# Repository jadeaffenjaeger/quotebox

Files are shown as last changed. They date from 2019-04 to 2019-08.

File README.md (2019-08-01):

## Quotebox
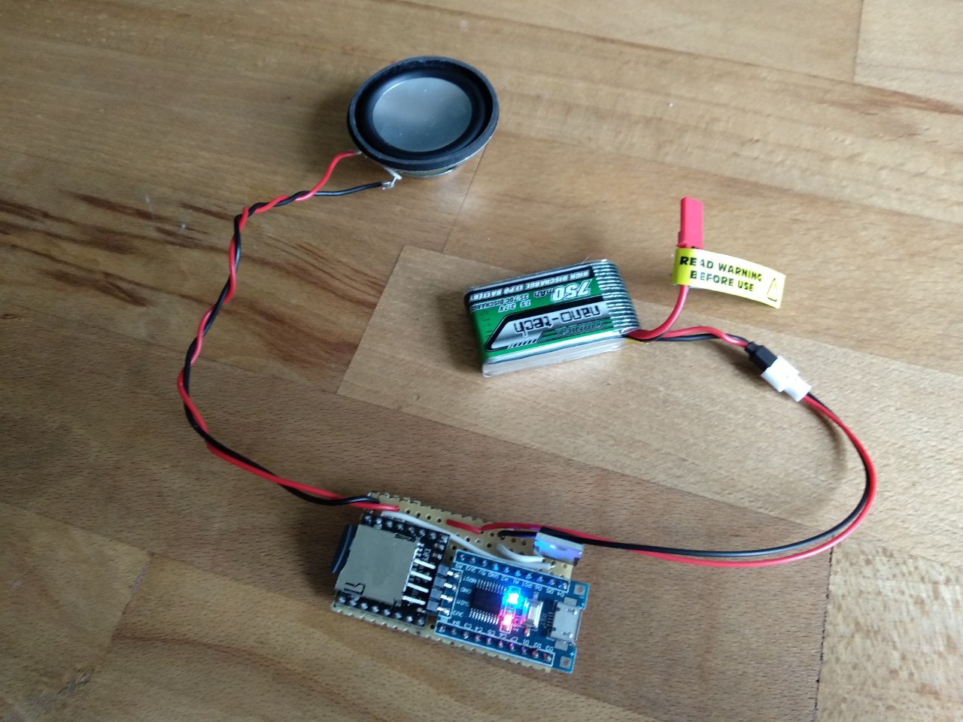
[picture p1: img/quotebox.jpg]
Quotebox Picture

This piece of electronics was made for an installation where speakers at various places would play short bits of sound at random intervals. Since there was no power available, the speakers need to run off 1S LiPo batteries. Since the budget was quite low, only cheap and easy to source components were used.

### Components
A DFPlayer mini module is used to play mp3 sound bites from an SD card. Since the Idle Power consumption of the DFPlayer is quite high, even when in Standby mode, an external STM8 microcontroller is used to power up the DFPlayer through a MOSFET when needed and power it down as soon as it has finished playing. The STM8 also keeps track of sleep times and which track on the card to play next.
The components used are:
- [DFPlayer Mini](https://wiki.dfrobot.com/DFPlayer_Mini_SKU_DFR0299)
- [STM8S103 Breakout Board](https://github.com/TG9541/stm8ef/wiki/Breakout-Boards#stm8s103f3p6-breakout-board)
- [IRLZ44N MOSFET](http://www.irf.com/product-info/datasheets/data/irlz44n.pdf)
- [HobbyKing 1S 750mAh LiPo](https://hobbyking.com/en_us/turnigy-nano-tech-750mah-1s-35-70c-lipo-pack-fits-nine-eagles-solo-pro-180.html)

summing up to below 5€ per speaker (without battery)

### Energy
750mAh LiPo batteries from HobbyKing were used to power each speaker as I had them laying around from my drone anyway. Both the STM8 and DFPlayer work with 3-5V, so no voltage regulator was needed, keeping the price down. The voltage of the LiPo is not checked by the microcontroller, however, so the circuit will deep-discharge the battery if left unattended for too long. For our use case, the speakers played a sound of ca. 5s every few minutes. The STM8 needs ca. 2mA when in sleep mode (mostly
due to the power LED on the breakout board. If lower consumption is required, one should remove the LED). The DFPlayer consumes 50-120mA when playing a file (depending on the content of the file). All in all, the speakers would have been able to work for 2-3 days on a single LiPo.

### Firmware
The firmware for the STM8 is in the `src` folder. The DFPlayer is addressed over UART via the `dfplayer.c` module, the `awu.c` sends the microcontroller to sleep and the external MOSFET that powers the DFPlayer on and off is switched in the `gpio.c` file, along with the user LED.
The firmware can be built with SDCC using `make all` and uploaded to a board with `make flash`. An STLink (clone) and [stm8flash] are required for this. If you run into problems uploading to a new board, you might try unlocking it using `make unlock`

[stm8flash]: https://github.com/vdudouyt/stm8flash

### Schematics
I tried started doing a custom PCB for the speakers, but ended up opting for Perf Board eventually. The PCB layout therefore is not up to date and should not be used as is.

### Housing
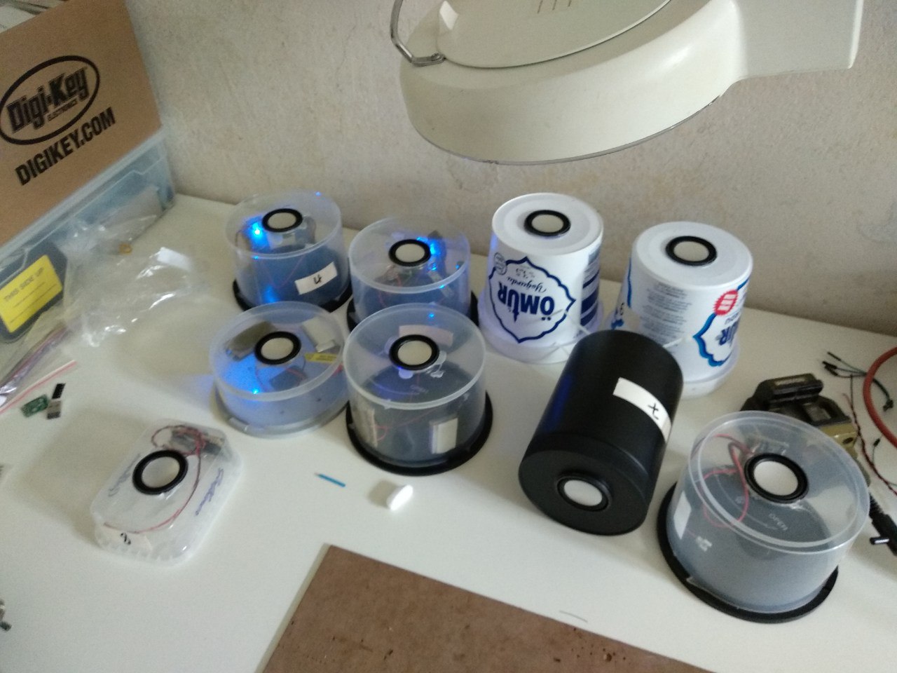
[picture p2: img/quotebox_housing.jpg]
Quotebox Housing

Again, to keep cost low, the speakers were hot-glued into old CD-R spindles to give them some protection and improve the resonance of the speaker

### Summary
The speakers at full volume were loud enough to be heard indoors. The ones installed outdoors (in a rather noisy environment) were quite hard understand from a few meters away already, so a bigger speaker and amp would be required for this to work.

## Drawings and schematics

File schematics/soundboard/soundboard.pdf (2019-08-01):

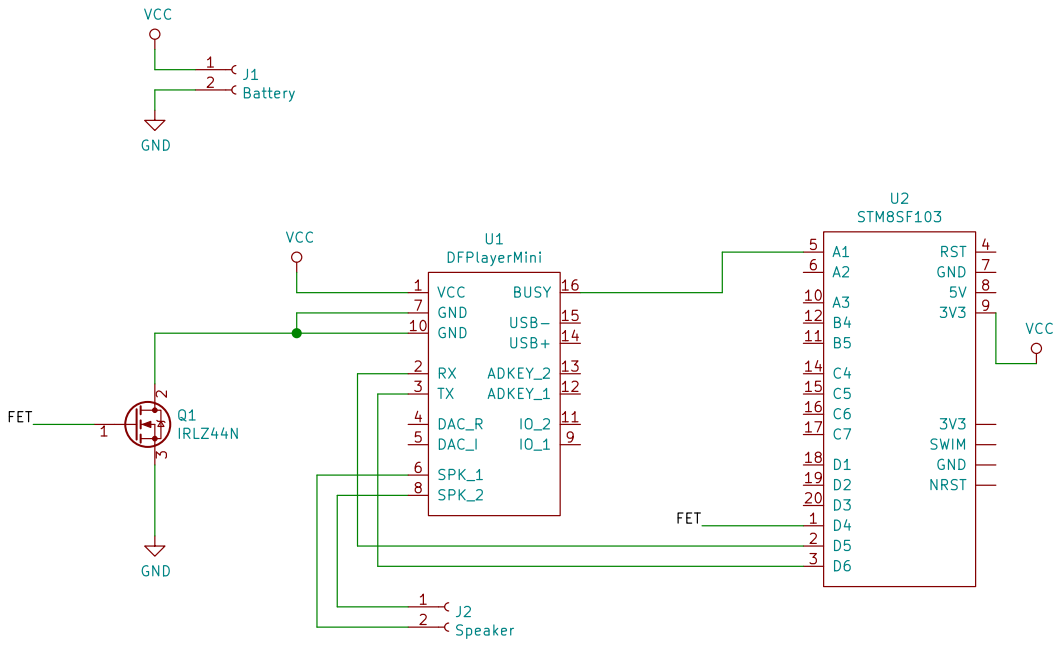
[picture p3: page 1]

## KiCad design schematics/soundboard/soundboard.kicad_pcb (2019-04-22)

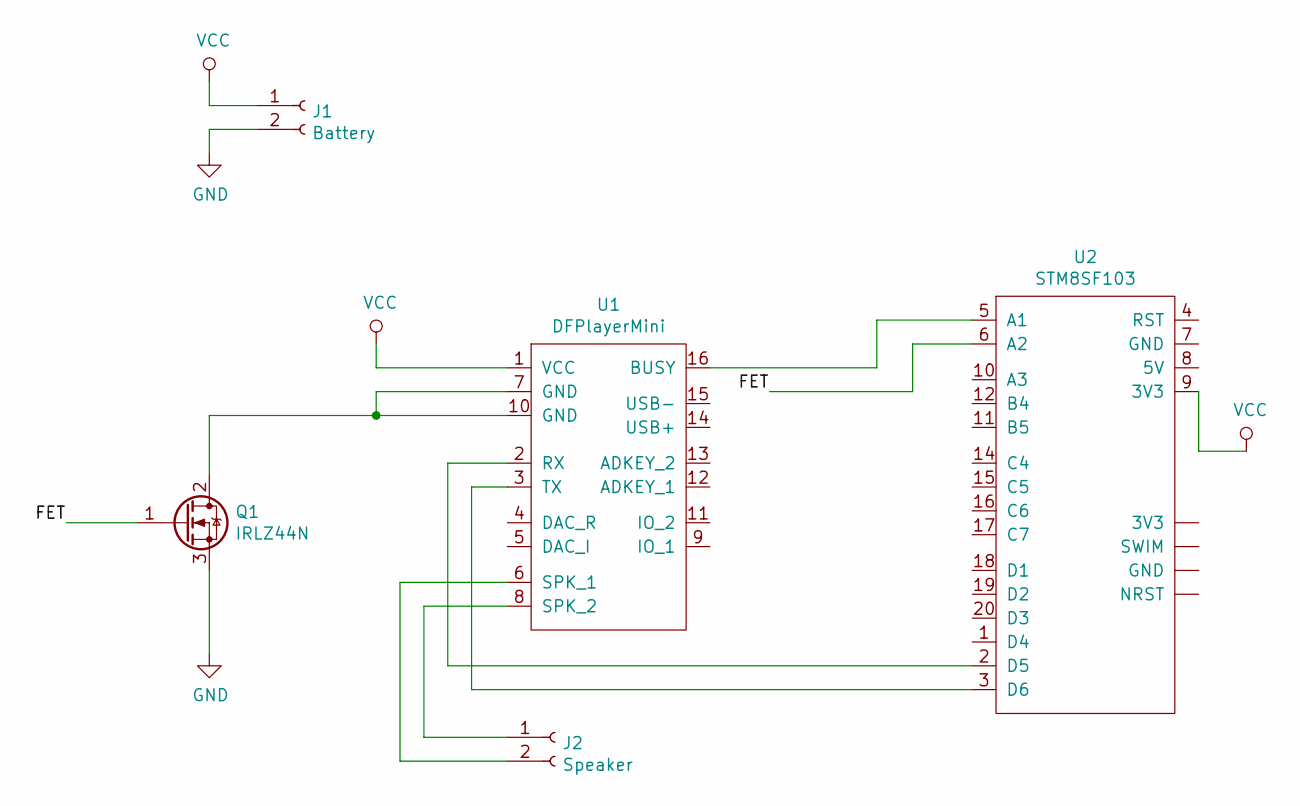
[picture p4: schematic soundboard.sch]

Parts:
J1: Battery; PinHeader_1x02_P2.54mm_Vertical
J2: Speaker; PinHeader_1x02_P2.54mm_Vertical
Q1: IRLZ44N; TO-220-3_Vertical
U1: DFPlayerMini; DFPlayer
U2: STM8SF103; STM8S103

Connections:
/FET: Q1.1 (G), U2.6 (A2)
GND: J1.2, Q1.3 (S)
unnamed: J2.1, U1.8 (SPK_2)
unnamed: J2.2, U1.6 (SPK_1)
unnamed: Q1.2 (D), U1.7 (GND), U1.10 (GND)
unnamed: U1.2 (RX), U2.2 (D5)
unnamed: U1.3 (TX), U2.3 (D6)
unnamed: U1.16 (BUSY), U2.5 (A1)
VCC: J1.1, U1.1 (VCC), U2.9 (3V3)

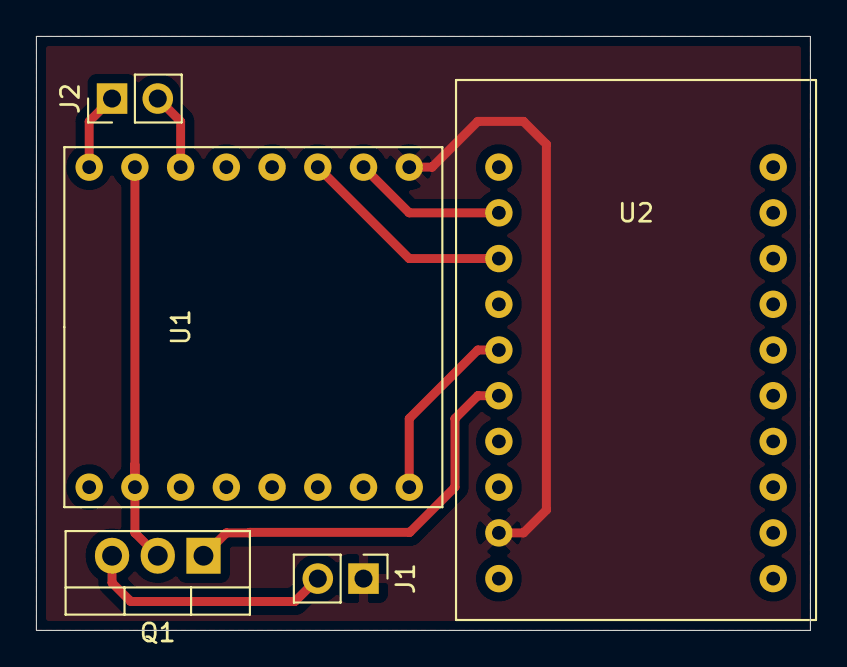
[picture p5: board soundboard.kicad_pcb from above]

Board: 2 copper layers, 43.0 x 33.0 mm, 5 parts (0 on the bottom side), 9 nets.

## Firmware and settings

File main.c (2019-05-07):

#include "stm8s.h"

#include "clock.h"
#include "uart.h"
#include "awu.h"
#include "gpio.h"
#include "lfsr.h"
#include "dfplayer.h"

#define ARR_LEN(x) (sizeof(x)/sizeof(x[0]))
#define VOLUME 20

void start_player();
void stop_player();

void main() {

    /* Delays to go to sleep for*/
#ifdef DEBUG
    uint16_t sleep_times[] = {5, 6, 3, 2, 1, 5};

#else
    uint16_t sleep_times[] = {
            211, 191, 204, 225, 229, 
            197, 275, 244, 183, 187, 
            282, 267, 297, 182, 292, 
            255, 266, 252, 184, 242, 
            208, 279, 295, 288, 211, 
            298, 249, 277, 246, 256 
    };
#endif

    uint8_t sleep_idx = 0;
    uint8_t track_idx = 1;

    /* Bring up hardware peripherals*/
    clock_init();
    uart_init();
    dfplayer_init();
    gpio_init();

    /* Get number of tracks on SD card to loop through*/
    start_player();
    uint16_t tracks = dfplayer_get_tracks();

    for(;;) {
        /* Bring up player*/
        gpio_led_on();
        start_player();

        /* Play next track*/
        dfplayer_set_track(track_idx++);
        if (track_idx > tracks) {
            track_idx = 1;
        }

        /* wait for Player to finish*/
        do {
            awu_sleep(MSECONDS_100);
        } while(gpio_player_busy() == true);

        /* shut down player*/
        stop_player();
        gpio_led_off();

        /* Go to sleep for next interval*/
        awu_sleep_n_seconds(sleep_times[sleep_idx++]);
        sleep_idx %= ARR_LEN(sleep_times);
    }
}

/* Do the necessary steps for the DFPlayer to be ready*/
void start_player() {
    gpio_fet_on();
    dfplayer_reset();
    dfplayer_wait_for_init();
    dfplayer_set_volume(VOLUME);
}

/* Shut down DFPlayer*/
void stop_player() {
    gpio_fet_off();
}

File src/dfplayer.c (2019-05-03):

#include "dfplayer.h"

static volatile dfplayer_t dfplayer_request = {
    .start = 0x7E,
    .version = 0xFF,
    .length = 6,
    .end = 0xEF
};

static volatile dfplayer_t dfplayer_response = {
    .start = 0x7E,
    .version = 0xFF,
    .length = 6,
    .end = 0xEF
};

static void _update_checksum() {

    volatile int16_t acc = 0;

    acc += dfplayer_request.version;
    acc += dfplayer_request.length;
    acc += dfplayer_request.command;
    acc += dfplayer_request.feedback;
    acc += dfplayer_request.param_H;
    acc += dfplayer_request.param_L;

    acc = -acc;

    dfplayer_request.checksum_H = acc >> 8;
    dfplayer_request.checksum_L = acc;
}

void _send_command(dfplayer_cmd_t command, uint16_t param) {

    dfplayer_request.command = (uint8_t) command;
    dfplayer_request.param_H = (param >> 8);
    dfplayer_request.param_L = param;
    _update_checksum();

    uart_send_buf((const uint8_t *) dfplayer_request, sizeof(dfplayer_t));
}

bool _get_response() {

    /* Wait for start*/
    while(uart_receive() != 0x7E);

    if(uart_receive() != dfplayer_response.version) return false;
    if(uart_receive() != dfplayer_response.length) return false;

    dfplayer_response.command = uart_receive();
    dfplayer_response.feedback = uart_receive();
    dfplayer_response.param_H = uart_receive();
    dfplayer_response.param_L = uart_receive();
    dfplayer_response.checksum_H = uart_receive();
    dfplayer_response.checksum_L = uart_receive();

    if(uart_receive() != dfplayer_response.end) return false;

    //TODO: Check checksum
    return true;
}

void dfplayer_init() {

}

uint16_t dfplayer_get_tracks() {
    _send_command(0x48, 0);
    _get_response();
    return (dfplayer_response.param_H << 8 | dfplayer_response.param_L);
}

void dfplayer_set_volume(uint8_t volume) {
    if (volume > 30) {
        volume = 30;
    }
    _send_command(CMD_SET_VOL, volume);
}

void dfplayer_standby() {
    _send_command(CMD_STDBY, 0);
}

void dfplayer_wakeup() {
    _send_command(CMD_NORMAL, 0);
}

void dfplayer_play() {
    _send_command(CMD_PLAY, 0);
}

void dfplayer_reset() {
    _send_command(CMD_RESET, 0);
}

void dfplayer_set_track(uint16_t num) {
    _send_command(CMD_NUM, num);
}

void dfplayer_playback_mode(dfplayer_mode_t mode) {
    _send_command(CMD_PLAYBACK_MODE, (uint16_t) mode);
}

void dfplayer_set_SD() {
    _send_command(CMD_PLAYBACK_SRC, 0);
}

bool dfplayer_wait_for_init() {
    bool response = _get_response();

    if(response == false) {
        return false;
    }

    // Response is error message
    if(dfplayer_response.command == 0x40) {
        return false;
    }

    return true;
}

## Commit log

2019-04-14 WIP: Get track count from player
2019-04-21 Add MOSFET control to GPIO
2019-04-21 Enable and disable Player via external MOSFET
2019-04-22 Add gitignore for KiCad files
2019-04-22 Add board schematics
    [soundboard.kicad_pcb, soundboard.sch]
2019-04-22 Add filled zone and outlines
    [soundboard.kicad_pcb]
2019-04-28 Change Pin mappings for FET and add BUSY pin
2019-04-29 Change mapping of FET to PD4
2019-08-01 Update FET pin in schematic
    [soundboard.sch]
2019-08-01 Add schematic as PDF
2019-08-01 Add note about outdated PCB layout
